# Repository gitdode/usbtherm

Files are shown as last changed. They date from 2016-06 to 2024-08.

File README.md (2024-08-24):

# USBTherm
Simple micro controller based USB thermometer with Linux kernel driver module and simple Java desktop app

This repository contains four projects:

* usbtherm-avr - USB thermometer based on an AVR micro controller and the https://github.com/obdev/v-usb firmware-only USB implementation
* usbtherm-kicad - KiCad project including schematic and PCB layout and a board at https://oshpark.com/shared_projects/ln73noyo
* usbtherm-linux - Basic but complete Linux kernel USB character device driver module
* usbtherm-libusb - Minimal interface to the device using libusb (much simpler and portable alternative to the Linux driver)
* usbtherm-ui - Simple Java desktop application displaying the temperature

A detailed description of the project can be found at http://luniks.net/usbtherm.jsp

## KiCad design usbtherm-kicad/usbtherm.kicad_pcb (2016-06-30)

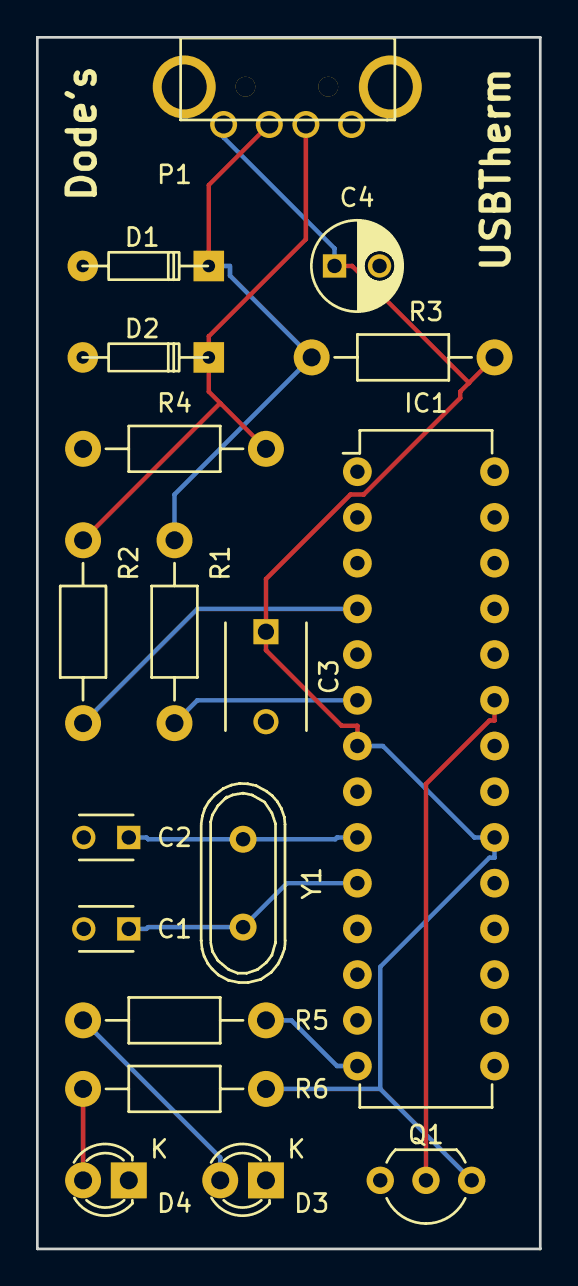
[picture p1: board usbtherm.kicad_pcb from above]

Board: 2 copper layers, 27.9 x 67.3 mm, 18 parts (0 on the bottom side), 12 nets.

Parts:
C1, C2: 22pF; C_Disc_D3_P2.5
C3: 100nF; C_Disc_D6_P5
C4: 10uF; C_Radial_D5_L6_P2.5
D1, D2: 3.6V; Diode_DO-35_SOD27_Horizontal_RM7
D3: Blue; LED-3MM
D4: Red; LED-3MM
IC1: ATMEGA328-P; DIP-28_W7.62mm
P1: USB_A_PLUG; USB_A_PLUG_CIRCULAR
Q1: TMP36; TO-92_Inline_Wide
R1, R2: 68; Resistor_Horizontal_RM10mm
R3: 1.5K; Resistor_Horizontal_RM10mm
R4: 1M; Resistor_Horizontal_RM10mm
R5, R6: 220; Resistor_Horizontal_RM10mm
Y1: 12 MHz; Crystal_HC49-U_Vertical

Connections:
GND: C1.2, C2.2, C3.2, C4.2, D1.2, D2.2, D3.1, D4.1, IC1.8, IC1.22, P1.4, Q1.3, R4.2
unnamed: C1.1, IC1.10, Y1.1
unnamed: C2.1, IC1.9, Y1.2
unnamed: C3.1, C4.1, IC1.7, IC1.20, P1.1, Q1.1, R3.1, R6.1
unnamed: D1.1, P1.2, R1.1, R3.2
unnamed: D2.1, P1.3, R2.1, R4.1
unnamed: D3.2, R5.1
unnamed: D4.2, R6.2
unnamed: IC1.4, R2.2
unnamed: IC1.6, R1.2
unnamed: IC1.14, R5.2
unnamed: IC1.23, Q1.2

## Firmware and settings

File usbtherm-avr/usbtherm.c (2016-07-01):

/*
 * usbtherm.c
 *
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
 * Firmware for USBTherm, a simple AVR micro controller based USB thermometer.
 *
 * Created on: 26.05.2016
 *     Author: dode@luniks.net
 *
 */

#include <stdbool.h>
#include <stdlib.h>
#include <stdio.h>
#include <avr/io.h>
#include <avr/interrupt.h>
#include <avr/pgmspace.h>
#include <avr/sleep.h>
#include <avr/wdt.h>
#include <util/delay.h>

#include "usbdrv/usbdrv.h"
/* #include "usbdrv/oddebug.h" */

/*
 * Simple module providing functions to print and read a string via USART.
 * Maybe not working for all AVR controllers.
 * The V-USB module "usbdrv/oddebug.h" provides more advanced debug logging.
 */
#include "usart.h"

/* The pins for V-USB are set up in usbdrv/usbconfig.h */
#define DDR_LED			DDRB
#define	PORT_LED		PORTB
#define PIN_LED			PB0
#define PIN_TEMP 		PC0
#define AREF_MV			5000

/* Weight of the exponential weighted moving average as bit shift */
#define EWMA_BS			2

/* Output of the TMP36 is 750 mV @ 25°C, 10 mV per °C */
#define TMP36_MV_0C		500
#define TMP36_MV_20C	700

/* Timer0 interrupts per second */
#define INTS_SEC 		F_CPU / (1024UL * 255)

/* Request from the kernel driver */
#define CUSTOM_REQ_TEMP	0

static volatile uint8_t ints = 0;
static int32_t mVAvg = TMP36_MV_20C << EWMA_BS;

ISR(TIMER0_COMPA_vect) {
	ints++;
}

EMPTY_INTERRUPT(ADC_vect);

/**
 * Sets up the pins.
 */
static void initPins(void) {
	// set LED pin as output pin
	DDR_LED |= (1 << PIN_LED);
}

/**
 * Sets up the timer.
 */
static void initTimer(void) {
	// timer0 clear timer on compare match mode, TOP OCR0A
	TCCR0A |= (1 << WGM01);
	// timer0 clock prescaler/1024/255 ~ 46 Hz @ 12 MHz ~ 61 Hz @ 16 MHz
	TCCR0B |= (1 << CS02) | (1 << CS00);
	OCR0A = 255;

	// enable timer0 compare match A interrupt
	TIMSK0 |= (1 << OCIE0A);
}

/**
 * Sets up the ADC.
 */
static void initADC(void) {
	set_sleep_mode(SLEEP_MODE_IDLE);

	// use AVCC as reference voltage
	ADMUX |= (1 << REFS0);
	// disable digital input on the ADC inputs to reduce digital noise
	DIDR0 = 0b00111111;
	// ADC clock prescaler/64 ~ 187.5 kHz @ 12 MHz ~ 250 kHz @ 16 MHz
	ADCSRA |= (1 << ADPS2) | (1 << ADPS1);
	// enable ADC interrupt
	ADCSRA |= (1 << ADIE);
	// enable ADC
	ADCSRA |= (1 << ADEN);
	// measure at pin PIN_TEMP
	ADMUX = (0b11110000 & ADMUX) | PIN_TEMP;
}

/**
 * Sets up V-USB.
 */
static void initUSB(void) {
	wdt_disable();
	usbInit();
	usbDeviceDisconnect();
	_delay_ms(255);
	usbDeviceConnect();
}

/**
 * Measures the voltage of the temperature sensor with 16x oversampling during
 * idle sleep mode to reduce digital noise, and calculates an exponential
 * weighted moving average.
 */
static void measureTemp(void) {
	uint32_t overValue = 0;
	for (uint8_t i = 0; i < 16; i++) {
		ADCSRA |= (1 << ADSC);
		sleep_mode();
		overValue += ADC;
	}

	int16_t mV = (((overValue >> 2) * AREF_MV) >> 12);

	// calculate EWMA
	mVAvg = mV + mVAvg - ((mVAvg - EWMA_BS) >> EWMA_BS);
}

/**
 * Translates the averaged voltage to degrees Celsius and prints the result.
 */
static void printTemp(void) {
	div_t temp = div((mVAvg >> EWMA_BS) - TMP36_MV_0C, 10);
	char buf[16];
	snprintf(buf, sizeof(buf), "%d.%d °C\n", temp.quot, abs(temp.rem));
	printString(buf);
}

/**
 * Called by the driver to read the temperature value in °C x10.
 */
uchar usbFunctionRead(uchar *data, uchar len) {

	/**
	 * The temperature value is short enough to be read at once.
	 * TODO okay like that?
	 */
	int16_t tempx10 = (mVAvg >> EWMA_BS) - TMP36_MV_0C;
	snprintf((char *)data, len, "%d", tempx10);

	return len;
}

/**
 * Sets up the implemented requests.
 */
usbMsgLen_t usbFunctionSetup(uchar data[8]) {
	usbRequest_t *req = (void *)data;

	/*
	 * The only implemented request - tells the driver to read data
	 * (the temperature value) with usbFunctionRead().
	 * Also, USB_CFG_IMPLEMENT_FN_READ must be set to 1 in usbdrv/usbconfig.h.
	 */
	if (req->bRequest == CUSTOM_REQ_TEMP) {
		return USB_NO_MSG;
	}

	/**
	 * Return no data for unimplemented requests.
	 */
	return 0;
}

int main(void) {

	// enable USART RX complete interrupt 0
	// UCSR0B |= (1 << RXCIE0);
	initUSART();
	initPins();
	initTimer();
	initADC();
	initUSB();

	// enable global interrupts
	sei();

	while (true) {

		/**
		 * About every second, turn on the LED, measure the temperature,
		 * print the temperature via USART, turn off the LED.
		 */
		if (ints >= INTS_SEC) {
			ints = 0;
			// set LED pin high
			PORT_LED |= (1 << PIN_LED);
			measureTemp();
			printTemp();
			// set LED pin low
			PORT_LED &= ~(1 << PIN_LED);

		}
		usbPoll();
	}

	return 0;
}

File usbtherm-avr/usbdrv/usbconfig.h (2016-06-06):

/* Name: usbconfig.h
 * Project: V-USB, virtual USB port for Atmel's(r) AVR(r) microcontrollers
 * Author: Christian Starkjohann
 * Creation Date: 2005-04-01
 * Tabsize: 4
 * Copyright: (c) 2005 by OBJECTIVE DEVELOPMENT Software GmbH
 * License: GNU GPL v2 (see License.txt), GNU GPL v3 or proprietary (CommercialLicense.txt)
 */

#ifndef __usbconfig_h_included__
#define __usbconfig_h_included__

/*
General Description:
This file is an example configuration (with inline documentation) for the USB
driver. It configures V-USB for USB D+ connected to Port D bit 2 (which is
also hardware interrupt 0 on many devices) and USB D- to Port D bit 4. You may
wire the lines to any other port, as long as D+ is also wired to INT0 (or any
other hardware interrupt, as long as it is the highest level interrupt, see
section at the end of this file).
+ To create your own usbconfig.h file, copy this file to your project's
+ firmware source directory) and rename it to "usbconfig.h".
+ Then edit it accordingly.
*/

/* ---------------------------- Hardware Config ---------------------------- */

#define USB_CFG_IOPORTNAME      D
/* This is the port where the USB bus is connected. When you configure it to
 * "B", the registers PORTB, PINB and DDRB will be used.
 */
#define USB_CFG_DMINUS_BIT      4
/* This is the bit number in USB_CFG_IOPORT where the USB D- line is connected.
 * This may be any bit in the port.
 */
#define USB_CFG_DPLUS_BIT       2
/* This is the bit number in USB_CFG_IOPORT where the USB D+ line is connected.
 * This may be any bit in the port. Please note that D+ must also be connected
 * to interrupt pin INT0! [You can also use other interrupts, see section
 * "Optional MCU Description" below, or you can connect D- to the interrupt, as
 * it is required if you use the USB_COUNT_SOF feature. If you use D- for the
 * interrupt, the USB interrupt will also be triggered at Start-Of-Frame
 * markers every millisecond.]
 */
#define USB_CFG_CLOCK_KHZ       (F_CPU/1000)
/* Clock rate of the AVR in kHz. Legal values are 12000, 12800, 15000, 16000,
 * 16500, 18000 and 20000. The 12.8 MHz and 16.5 MHz versions of the code
 * require no crystal, they tolerate +/- 1% deviation from the nominal
 * frequency. All other rates require a precision of 2000 ppm and thus a
 * crystal!
 * Since F_CPU should be defined to your actual clock rate anyway, you should
 * not need to modify this setting.
 */
#define USB_CFG_CHECK_CRC       0
/* Define this to 1 if you want that the driver checks integrity of incoming
 * data packets (CRC checks). CRC checks cost quite a bit of code size and are
 * currently only available for 18 MHz crystal clock. You must choose
 * USB_CFG_CLOCK_KHZ = 18000 if you enable this option.
 */

/* ----------------------- Optional Hardware Config ------------------------ */

/* #define USB_CFG_PULLUP_IOPORTNAME   D */
/* If you connect the 1.5k pullup resistor from D- to a port pin instead of
 * V+, you can connect and disconnect the device from firmware by calling
 * the macros usbDeviceConnect() and usbDeviceDisconnect() (see usbdrv.h).
 * This constant defines the port on which the pullup resistor is connected.
 */
/* #define USB_CFG_PULLUP_BIT          4 */
/* This constant defines the bit number in USB_CFG_PULLUP_IOPORT (defined
 * above) where the 1.5k pullup resistor is connected. See description
 * above for details.
 */

/* --------------------------- Functional Range ---------------------------- */
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

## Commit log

2016-05-28 added USART module, initial implementation of measuring temperature with a TMP36
2016-05-29 added usb_driver probe and disconnect
2016-05-29 using usb_class_driver and module_usb_driver, added "opening" and reading something from the USB device
2016-05-31 implemented reading from the device
2016-06-03 simplified makefile, added LED that flashes when the temperature is measured
2016-06-04 create the device file with permissions 644 so it is readable by everyone
2016-06-04 put test dependencies to scope test, moved temperature format to constant
2016-06-04 fixed function device_read; don't read more than there is (NUL character)
    [usbtherm.c]
2016-06-06 use custom private vendor and product id actually used by the device, read temperature value from device
2016-06-06 run with 16 MHz, changed device name, implemented status request to read temperature value, small improvements
2016-06-06 divide temperature value by 10
2016-06-08 make device node writeable for everyone, formatting
2016-06-12 added initial PCB design with KiCad
    [unrouted.kicad_pcb, usbtherm.kicad_pcb, usbtherm.sch]
2016-06-12 replaced USB connector with plug, created footprint for it, added board edges, autorouted with FreeRouting, fixed offset of 3D model of resistors
    [unrouted.kicad_pcb, usbtherm.dsn, usbtherm.kicad_pcb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]
2016-06-12 set PIN_LED to PB0 according to schematic
2016-06-14 fixed 2 DRC warnings, added ground plane
    [usbtherm.kicad_pcb]
2016-06-14 modified the silk screen of the USB plug to not extend the board edges and changed the oval drills for the shield pins to circular so it looks okay at OSHPark
    [usbtherm.kicad_pcb]
2016-06-14 gitignore files created during build, added short description
    [usbtherm.c]
2016-06-15 fixed function device_read
2016-06-15 moved the KiCad project to its own project
    [usbtherm.dsn, usbtherm.kicad_pcb, usbtherm.sch]
2016-06-29 removed link to broken PCB
2016-06-30 added link to board with fixed layout
2016-06-30 fixed wrong USB plug pin layout, other minor layout improvements, removed redundant include
    [usbtherm.dsn, usbtherm.kicad_pcb]
2017-05-01 allocate URB transfer buffer in kernel memory instead of using on-stack buffer to avoid error with "transfer buffer not dma capable" since Kernel 4.9
    [usbtherm.c]
2018-10-21 use strlcpy to avoid -Wstringop-truncation
    [usbtherm.c]
2020-01-04 log error when transfer failed
    [usbtherm.c]
2021-06-06 update, include .travis.yml in usbtherm-ui
    [usbtherm-2019-04-05-23-38-15.sch]
2021-06-06 see if the Linux driver can be built as well :-)
2023-01-22 increase usb transfer buffer to 16 bytes for temperature and humidity
2024-08-24 Fix build with recent Kernel 6.10
    [usbtherm.c]

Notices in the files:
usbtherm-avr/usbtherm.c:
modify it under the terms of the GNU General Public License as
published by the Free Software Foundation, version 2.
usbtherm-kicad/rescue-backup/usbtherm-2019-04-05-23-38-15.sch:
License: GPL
